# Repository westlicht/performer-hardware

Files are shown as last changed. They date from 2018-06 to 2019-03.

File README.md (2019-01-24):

# PER|FORMER - Hardware Design Files

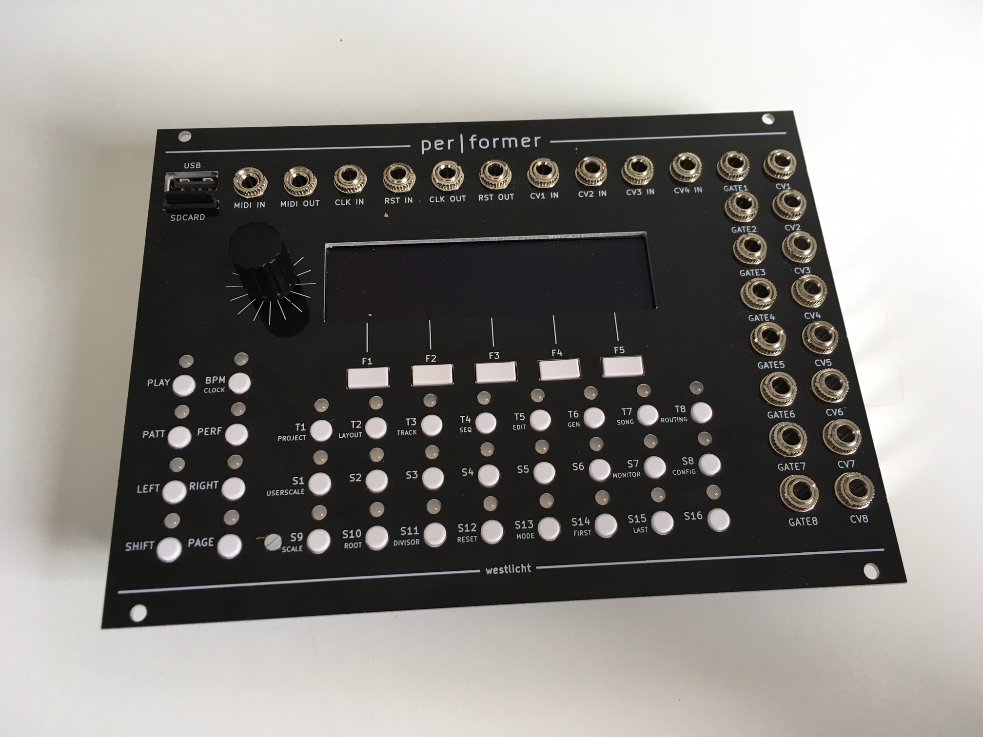
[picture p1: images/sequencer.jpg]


## Overview

This repository contains the hardware design files (KiCad) for the **PER|FORMER** eurorack sequencer.

For more information on the project go [here](https://westlicht.github.io/performer).

The firmware is hosted in a separate repository [here](https://github.com/westlicht/performer).

## Schematic

The schematic is available as a [PDF](https://cdn.rawgit.com/westlicht/performer-hardware/master/sequencer.pdf).

## Physical dimensions

| Board | Width (mm) | Height (mm) |
| --- | --- | --- |
| PCB | 171.45 | 106.68 |
| Frontpanel | 172.5 | 128.27 |

The width of the module is 34 HP in [eurorack standard](http://www.doepfer.de/a100_man/a100m_e.htm).

## Bill of materials

The BOM is available as a [CSV](bom/bom.csv) and [HTML](https://cdn.rawgit.com/westlicht/performer-hardware/master/bom/bom.html). In addition to the parts on the PCB there are a few additional hardware components that are necessary to complete the build, see [here](bom/hardware.csv).

## License

<br />

This work is licensed under a <a rel="license" href="http://creativecommons.org/licenses/by-nc-sa/4.0/">Creative Commons Attribution-NonCommercial-ShareAlike 4.0 International License</a>.

## Images

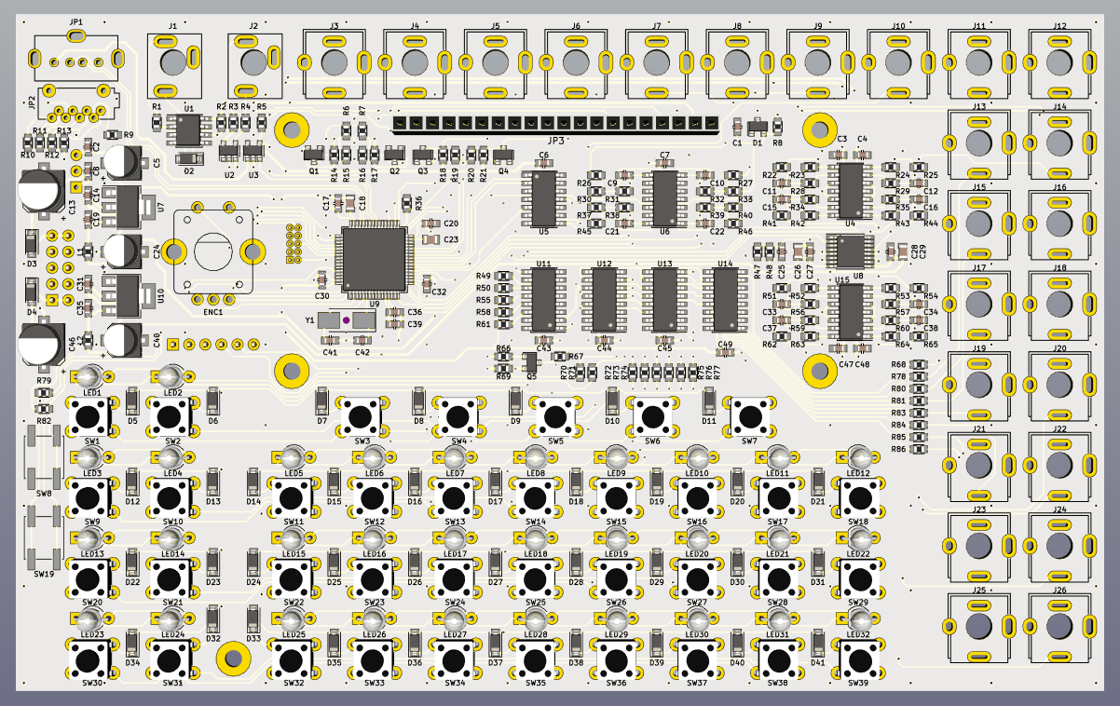
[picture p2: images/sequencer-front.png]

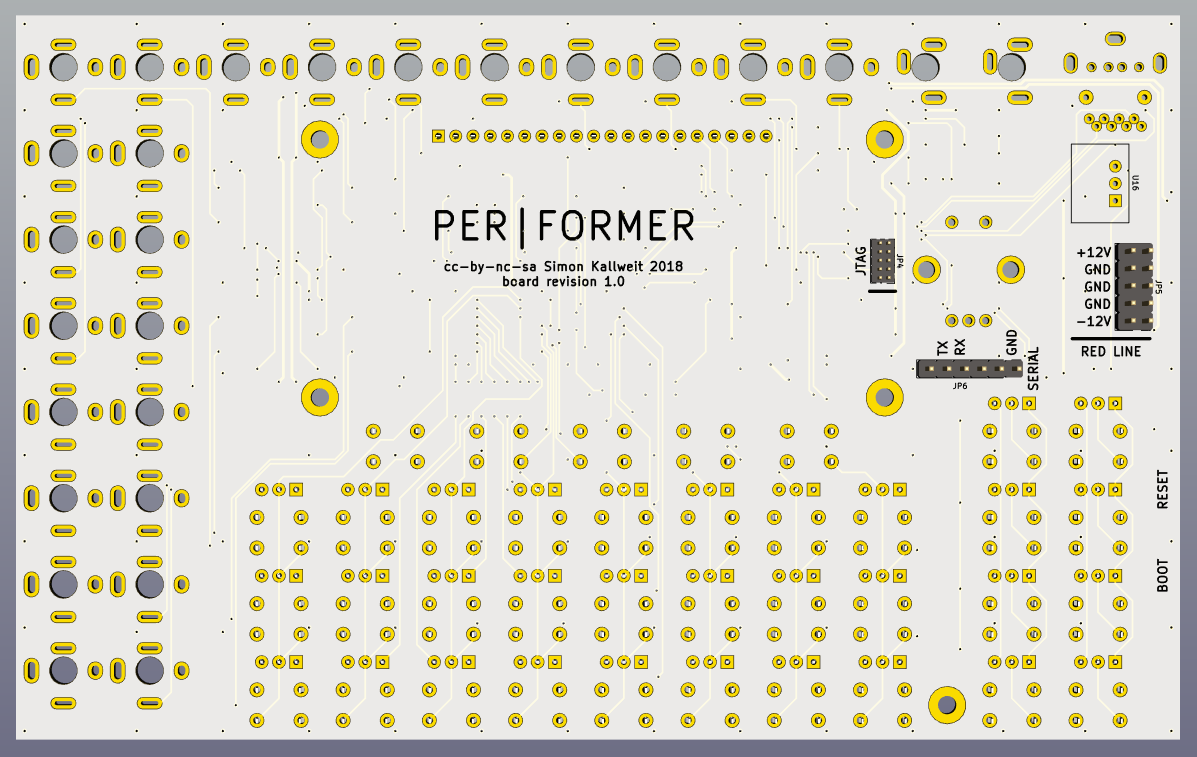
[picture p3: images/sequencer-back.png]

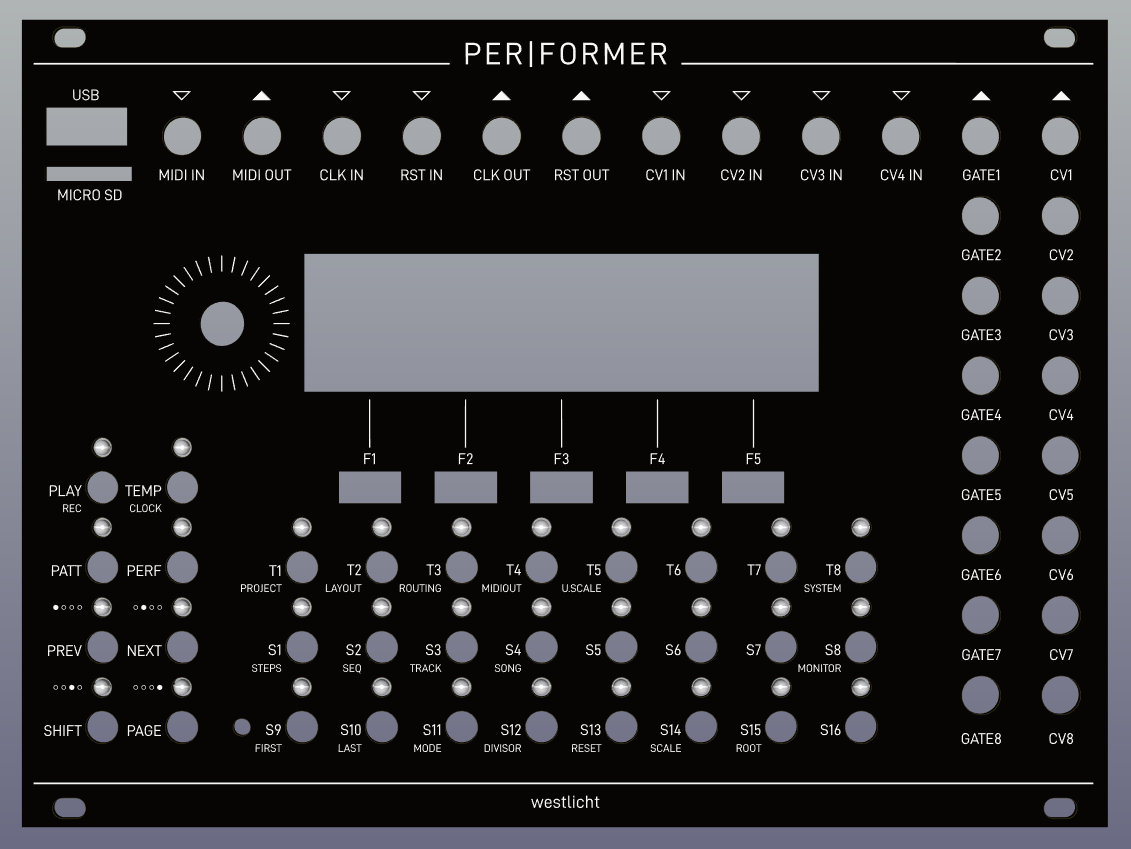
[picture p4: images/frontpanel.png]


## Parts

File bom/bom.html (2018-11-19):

Source File | /Users/freak/Documents/performer-hardware/sequencer.sch
BoM Date | 2018 November 19, Monday 22:16:32
Schematic Version | 1.0
Schematic Date | 2018-10-09
KiCad Version | Eeschema 4.0.7
Component Groups | 46
Component Count (per PCB) | 304
Fitted Components (per PCB) | 304
Number of PCBs | 1
Total Component Count (for 1 PCBs) | 304
 | References | Quantity Per PCB | Value | Package | MFN | MFP | Datasheet
1 | C1 C2 C3 C4 C6 C7 C8 C14 C17 C19 C20 C25 C27 C28 C30 C31 C32 C35 C36 C43 C44 C45 C47 C48 C49 | 25 | 100n | 0603 | Murata | GRM188R71E104JA01J | http://datasheet.octopart.com/GRM188R71E104JA01J-Murata-datasheet-66077098.pdf
2 | C11 C12 C15 C16 C33 C34 C37 C38 C41 C42 | 10 | 18p | 0603 | Murata | GRM1885C1H180JA01J | http://datasheet.octopart.com/GRM1885C1H180JA01J-Murata-datasheet-66077082.pdf
3 | C9 C10 C21 C22 | 4 | 1n | 0603 | Murata | GRM1885C1H102FA01J | http://datasheet.octopart.com/GRM1885C1H102FA01J-Murata-datasheet-66077081.pdf
4 | C39 | 1 | 1u | 0603 | Murata | GRM188R61A105KA61J | http://datasheet.octopart.com/GRM188R61A105KA61J-Murata-datasheet-66077091.pdf
5 | C18 C23 C26 C29 | 4 | 2.2u | 0805 | TDK | C2012X5R1A225K085AA | http://datasheet.octopart.com/C2012X5R1A225K085AA-TDK-datasheet-41194876.pdf
6 | C5 C24 C40 | 3 | 22u | Panasonic C | Panasonic | EEE-FP1E220AR | http://datasheet.octopart.com/EEE-FP1E220AR-Panasonic-datasheet-13268972.pdf
7 | C13 C46 | 2 | 47u | Panasonic D | Panasonic | EEE-FK1V470P | http://datasheet.octopart.com/EEE-FK1V470P-Panasonic-datasheet-13266987.pdf
8 | D2 D5 D6 D7 D8 D9 D10 D11 D12 D13 D14 D15 D16 D17 D18 D19 D20 D21 D22 D23 D24 D25 D26 D27 D28 D29 D30 D31 D32 D33 D34 D35 D36 D37 D38 D39 D40 D41 | 38 | 1N4148 | SOD-123 | Diodes Inc. | 1N4148W-7-F | http://datasheet.octopart.com/1N4148W-7-F-Diodes-Inc.-datasheet-12518151.pdf
9 | D3 D4 | 2 | 1N5819HW | SOD-123 | Diodes Inc. | 1N5819HW-7-F | http://datasheet.octopart.com/1N5819HW-7-F-Diodes-Inc.-datasheet-34441420.pdf
10 | D1 | 1 | LM4040CIM3-10.0 | SOT-23 | Texas Instruments | LM4040CIM3-10.0/NOPB | http://www.ti.com/product/lm4040-n/technicaldocuments?HQS=TI-null-null-octopart-df-pf-null-wwe
11 | ENC1 | 1 | PEC11R |  | Bourns | PEC11R-4220F-S0024 | http://datasheet.octopart.com/PEC11R-4220F-S0024-Bourns-datasheet-68303416.pdf
12 | J3 J4 J5 J6 J7 J8 J9 J10 J11 J12 J13 J14 J15 J16 J17 J18 J19 J20 J21 J22 J23 J24 J25 J26 | 24 | PJ301BM |  | Wenzhou QingPu Electronics | WQP-PJ301BM | http://www.qingpu-electronics.com/en/products/wqp-pj3010bm-34.html
13 | J1 J2 | 2 | PJ301CM |  | Wenzhou QingPu Electronics | WQP-PJ301CM | http://www.qingpu-electronics.com/en/products/WQP-PJ301CM-40.html
14 | JP4 | 1 | JTAG |  | FCI | 20021111-00010T4LF | http://datasheet.octopart.com/20021111-00010T4LF-FCI-datasheet-11548804.pdf
15 | JP3 | 1 | NHD-3.12-25664UC |  | Newhaven Display | NHD-3.12-25664UCY2 | http://datasheet.octopart.com/NHD-3.12-25664UCY2-Newhaven-Display-datasheet-10504909.pdf
16 | JP2 | 1 | PJS008U-3000 |  | Yamaichi | PJS008U-3000-0 | http://datasheet.octopart.com/PJS008U-3000-0-Yamaichi-datasheet-32042463.pdf
17 | JP5 | 1 | POWER |  | FCI | 67996-410HLF | http://datasheet.octopart.com/67996-410HLF-Areva-datasheet-10288749.pdf
18 | JP6 | 1 | Serial / Bootloader |  | FCI | 68002-106HLF | http://datasheet.octopart.com/68002-106HLF-FCI-datasheet-8449737.pdf
19 | JP1 | 1 | USB_A |  | Molex | 105057-0001 | http://datasheet.octopart.com/105057-0001-Molex-datasheet-48881000.pdf
20 | L1 L2 | 2 | Bead | 0603 | Laird | MI0603K300R-10 | http://datasheet.octopart.com/MI0603K300R-10-Steward-datasheet-14357321.pdf
21 | LED1 LED2 LED3 LED4 LED5 LED6 LED7 LED8 LED9 LED10 LED11 LED12 LED13 LED14 LED15 LED16 LED17 LED18 LED19 LED20 LED21 LED22 LED23 LED24 LED25 LED26 LED27 LED28 LED29 LED30 LED31 LED32 | 32 | LTL1BEKVJNN |  | Lite-On | LTL1BEKVJNN | http://datasheet.octopart.com/LTL1BEKVJNN-Lite-On-datasheet-25352782.pdf
22 | Q1 Q2 Q3 Q4 Q5 | 5 | MMBT3904 | SOT-23 | ON Semiconductor | MMBT3904LT1G | http://datasheet.octopart.com/MMBT3904LT1G-ON-Semiconductor-datasheet-11971584.pdf
23 | R14 R17 R26 R27 R28 R29 R34 R35 R45 R46 R56 R57 R59 R60 R69 | 15 | 100k | 0603 | Panasonic | ERJ-3EKF1003V | http://datasheet.octopart.com/ERJ-3EKF1003V-Panasonic-datasheet-82288794.pdf
24 | R2 R5 R6 R7 R19 R20 R36 R49 R50 R55 R58 R61 R66 R67 R79 R82 | 16 | 10k | 0603 | Panasonic | ERJ-3EKF1002V | http://datasheet.octopart.com/ERJ-3EKF1002V-Panasonic-datasheet-13266541.pdf
25 | R9 R15 R16 | 3 | 1M | 0603 | Panasonic | ERJ-3EKF1004V | http://datasheet.octopart.com/ERJ-3EKF1004V-Panasonic-datasheet-13266541.pdf
26 | R8 R18 R21 R68 R70 R71 R72 R73 R74 R75 R76 R77 R78 R80 R81 R83 R84 R85 R86 | 19 | 1k | 0603 | Panasonic | ERJ-3EKF1001V | http://datasheet.octopart.com/ERJ-3EKF1001V-Panasonic-datasheet-82288794.pdf
27 | R30 R33 R37 R40 | 4 | 200k | 0603 | Panasonic | ERJ-3EKF2003V | http://datasheet.octopart.com/ERJ-3EKF2003V-Panasonic-datasheet-13266541.pdf
28 | R1 R3 R4 R23 R24 R42 R43 R52 R53 R63 R64 | 11 | 220 | 0603 | Panasonic | ERJ-3EKF2200V | http://datasheet.octopart.com/ERJ3EKF2200V-Panasonic-datasheet-13266541.pdf
29 | R47 | 1 | 22k | 0603 | Panasonic | ERJ-3EKF2202V | http://datasheet.octopart.com/ERJ3EKF2202V-Panasonic-datasheet-13266541.pdf
30 | R22 R25 R41 R44 R51 R54 R62 R65 | 8 | 24k | 0603 | Panasonic | ERJ-3EKF2402V | http://datasheet.octopart.com/ERJ-3EKF2402V-Panasonic-datasheet-82288794.pdf
31 | R10 R11 R12 R13 R31 R32 R38 R39 R48 | 9 | 33k | 0603 | Panasonic | ERJ-3EKF3302V | http://datasheet.octopart.com/ERJ3EKF3302V-Panasonic-datasheet-13266541.pdf
32 | SW8 SW19 | 2 | EVQQ2 |  | Panasonic | EVQ-Q2K01W | http://datasheet.octopart.com/EVQ-Q2K01W-Panasonic-datasheet-13267673.pdf
33 | SW1 SW2 SW3 SW4 SW5 SW6 SW7 SW9 SW10 SW11 SW12 SW13 SW14 SW15 SW16 SW17 SW18 SW20 SW21 SW22 SW23 SW24 SW25 SW26 SW27 SW28 SW29 SW30 SW31 SW32 SW33 SW34 SW35 SW36 SW37 SW38 SW39 | 37 | TL1105 |  | E-Switch | TL1105SPF160Q | http://datasheet.octopart.com/TL1105SPF160Q-E-Switch-datasheet-502092.pdf
34 | U11 | 1 | 74HC165 | SOIC-16 | Texas Instruments | SN74HC165D | https://octopart.com/click/track?ct=datasheets&hlid=24916538&ppid=35776&sid=370&sig=03765d0
35 | U12 U13 U14 | 3 | 74HC595 | SOIC-16 | Texas Instruments | SN74HC595D | https://octopart.com/click/track?ct=datasheets&hlid=24917219&ppid=44183&sid=370&sig=036bbbe
36 | U5 | 1 | 74HCT125 | SOIC-14 | Texas Instruments | SN74HCT125D | https://octopart.com/click/track?ct=datasheets&hlid=24917456&ppid=464455&sid=370&sig=085083f
37 | U2 | 1 | 74LV1T34 | SOT-23-5 | Texas Instruments | SN74LV1T34DBVR | https://octopart.com/click/track?ct=datasheets&hlid=24919287&ppid=33260490&sid=370&sig=060f3df
38 | U8 | 1 | DAC8568C | TSSOP-16 | Texas Instruments | DAC8568ICPW | https://octopart.com/click/track?ct=datasheets&hlid=24881192&ppid=10447789&sid=370&sig=0a14fa8
39 | U7 U10 | 2 | LM1117-3.3 | SOT-223 | Texas Instruments | LM1117MP-3.3/NOPB | https://octopart.com/click/track?ct=datasheets&hlid=24885394&ppid=24812450&sid=370&sig=0f3ff9a
40 | U6 | 1 | MCP6004 | SOIC-14 | Microchip | MCP6004-I/SL | http://datasheet.octopart.com/MCP6004-I/SL-Microchip-datasheet-8823409.pdf
41 | U4 U15 | 2 | OPA4172 | SOIC-14 | Texas Instruments | OPA4172IDR | https://octopart.com/click/track?ct=datasheets&hlid=24903049&ppid=47153707&sid=370&sig=086dfac
42 | U16 | 1 | R-78E5.0-1.0 |  | Recom Power | R-78E5.0-1.0 | http://datasheet.octopart.com/R-78E5.0-1.0-Recom-Power-datasheet-68298118.pdf
43 | U9 | 1 | STM32F405RGTx | LQFP-64 | STMicroelectronics | STM32F405RGT6 | http://datasheet.octopart.com/STM32F405RGT6-STMicroelectronics-datasheet-12357803.pdf
44 | U3 | 1 | STMPS2151 | SOT-23-5 | STMicroelectronics | STMPS2151STR | http://datasheet.octopart.com/STMPS2151STR-STMicroelectronics-datasheet-15207125.pdf
45 | U1 | 1 | VO0600T | SOIC-8 | Vishay | VO0600T | http://datasheet.octopart.com/VO0600T-Vishay-datasheet-8549194.pdf
46 | Y1 | 1 | 8MHz |  | Abracon | ABM3-8.000MHZ-D2Y-T | http://datasheet.octopart.com/ABM3-8.000MHZ-D2Y-T-Abracon-datasheet-8815637.pdf

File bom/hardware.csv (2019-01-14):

Component | References | Quantity Per PCB | Value | MFP | MFN | Datasheet
1 | LCD Connector Female | 1 | 20P | 929870-01-20-RA | 3M | http://datasheet.octopart.com/929870-01-20-RA-3M-datasheet-167403.pdf
2 | LCD Connector Male | 1 | 20P | 68002-120HLF | FCI | http://datasheet.octopart.com/68002-120HLF-FCI-datasheet-8449737.pdf
3 | Round Switch Caps | 32 | 1RWHT | 1RWHT | E-Switch | http://datasheet.octopart.com/1RWHT-E-Switch-datasheet-12523944.pdf
4 | Rectangular Switch Caps | 5 | 1CWHT | 1CWHT | E-Switch | https://datasheet.octopart.com/1CWHT-E-Switch-datasheet-44138771.pdf
5 | Rotary Knob | - | - | - | - | https://www.thonk.co.uk/shop/sifam-soft-touch-encoder-knobs/
6 | M2.5 Standoff 7mm | 4 | - | R25-1000702 | Harwin | http://datasheet.octopart.com/R25-1000702-Harwin-datasheet-155401.pdf
7 | M2.5 Standoff 11mm | 1 | - | R25-1001102 | Harwin | http://datasheet.octopart.com/R25-1001102-Harwin-datasheet-14706888.pdf
8 | M2.5 Screw | 10 | 29300 | Keystone | http://datasheet.octopart.com/29300-Keystone-datasheet-43872458.pdf

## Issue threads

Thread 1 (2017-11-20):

Replace MCP6004 with TL074

westlicht, 2017-11-20:
MCP6004 has max +/-6V power supply, but it's sourced from +/-12V, so just replace with pin-compatible TL074.

Closed 2017-11-20.

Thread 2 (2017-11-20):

Replace 0603 footprints

westlicht, 2017-11-20:
0603 footprints are really small, especially for hand-soldering. Should be replaced with larger footprints for the DIY version!

Closed 2018-05-16.

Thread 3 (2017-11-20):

Fix USB connector cutout

westlicht, 2017-11-20:
The cutout on the frontpanel for the USB connector is too large.

Closed 2018-05-16.

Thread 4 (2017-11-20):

Fix PJ301CM footprint

westlicht, 2017-11-20:
While the footprint is correct, the alignment to the frontpanel cutout is not.

Closed 2019-03-19.

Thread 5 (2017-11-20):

Replace jack connectors with thonkiconns

westlicht, 2017-11-20:
Thonk will soon stock the stereo version of the thonkiconn jack, so this might be a better alternative to the current jacks.

westlicht, 2019-03-19:
The footprint is too large to make for a neat design. Will keep the jacks as is for now.

Closed 2019-03-19.

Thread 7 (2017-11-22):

Consider replacing DAC8568C with DAC8568A

westlicht, 2017-11-22:
The C grade have 5V full scale output, but due to VCC at 3.3V we only use half range at 2.5V and loose 1 bit of accuracy. We could replace with DAC8568A which has full range at 2.5V, so this would allow us to use all bits, however, we use some accuracy due to lower grade of internal reference.

8bitPig, 2019-08-20:
Aren't we loosing 8bits of accuracy?
Still worth the higher temp drift even considering the 33k/22k Voltage divider (each resistor has 100-150ppm) for Vbias which then gets gained times 4.

btomwhitehead, 2020-01-29:
Resurrecting an old issue here but thought I its a pertinent place to raise it. If you dont think so, Im happy to delete my comment.

I made the mistake of getting a DAC8568B, which like A, doesn't have the 2x output gain. I am not worried about the initialisation value being at midpoint given the firmware appears to init the Dac to 0v regardless.

So the two options are:
- Replace the DAC (and there will be an effective 15bit resolution)
- Update firmware to reflect the reduced output gain.

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

From my understanding of this issue and the effective output in the datasheet, it seems that the leading bit is irrelevant because the VCC is less than the 5v range. My thought it then that the gain can be made up with writing double the DATA value to the DAC. If this is true, if we reduce the right data bitwise shifts in the Dac write by 1, we can effectively make up the range:
```
void Dac::writeDac(uint8_t command, uint8_t address, uint16_t data, uint8_t function) {
    uint8_t b1 = command;
    uint8_t b2 = (address << 4) | (data >> 12);
    uint8_t b3 = data >> 4;
    uint8_t b4 = (data & 0xf) << 4 | function;
  ...
```
to
```
void Dac::writeDac(uint8_t command, uint8_t address, uint16_t data, uint8_t function) {
    uint8_t b1 = command;
    uint8_t b2 = (address << 4) | (data >> 11);
    uint8_t b3 = data >> 3;
    uint8_t b4 = ((data << 1) & 0xf) << 4 | function;
  ...
```
Do you think this could work? I am going to give it a test in the coming days. Or do you know a better place (this is no doubt a hack) to make such a change?

🙏 🙏 🙏

westlicht, 2020-03-29:
Hey, I only saw this comment now. I think the change you did is valid, shifting the output by one bit. I might consider adding that to the hardware config so people can actually use the cheaper DAC if the wish to. I haven't measured the difference in accuracy, would have to first make a performer with the A grade DAC.

btomwhitehead, 2020-03-29:
Great!

Yeah, I have been using it since without any complaints or noticeable drift.

Thanks for the response.

Timnuge, 2020-04-10:
Hello!

My Performer is built with DAC8568A🤔 A way to switch would make my life easy or, could you please share with me update file? Any help would be greatly appreciated!

btomwhitehead, 2020-04-10:
@Timnuge as per above notes, heres the changes I made to `src/platform/stm32/drivers/Dac.cpp`:

```
--- a/src/platform/stm32/drivers/Dac.cpp
+++ b/src/platform/stm32/drivers/Dac.cpp
@@ -72,9 +72,9 @@ void Dac::write() {

 void Dac::writeDac(uint8_t command, uint8_t address, uint16_t data, uint8_t function) {
     uint8_t b1 = command;
-    uint8_t b2 = (address << 4) | (data >> 12);
-    uint8_t b3 = data >> 4;
-    uint8_t b4 = (data & 0xf) << 4 | function;
+    uint8_t b2 = (address << 4) | (data >> 11);
+    uint8_t b3 = data >> 3;
+    uint8_t b4 = ((data << 1) & 0xf) << 4 | function;

     gpio_clear(DAC_PORT, DAC_SYNC);--- a/src/platform/stm32/drivers/Dac.cpp
```

Would have pushed a custom branch to the main repo but (very sensibly) I don't have the requisite permissions.

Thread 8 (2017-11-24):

Fix LED Matrix

westlicht, 2017-11-24:
The LED matrix is flawed. The 74HC595 cannot sink the current of 8 LEDs in a row. Possible solutions:
- sinking 74HC595 with a part like TPIC6x595
- add a darlington array to allow sinking more current

Make sure that sourcing current for the LEDs is within the specs of the 74HC595, otherwise we also need to increase sourcing capability.

westlicht, 2018-05-16:
Using low power leds instead.

Closed 2018-05-16.

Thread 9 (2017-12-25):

Replace 74HC with 74HCT

westlicht, 2017-12-25:
Use TTL versions of shift registers and remove the level shifter IC. Also, connect OE pins to STM32 to allow disabling the matrix.

westlicht, 2018-05-16:
Using lower power leds instead.

Closed 2018-05-16.

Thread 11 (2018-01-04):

Fix SDCard

westlicht, 2018-01-04:
- add 10k pullups to all signals
- move SDIO_CMD from pin 2 to pin 3
- add card detect line

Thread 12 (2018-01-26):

Rework power supply

westlicht, 2018-01-26:
The 5V regulator overheats due to excessive power dissipation. The linear regulator needs to replaced with a dc/dc step down regulator with higher efficiency.

- use step down to generate 5V at 1A for the whole module
- feed 3.3V regulators from the 5V supply
- a possible part is the RECOM R-78E-1.0 (https://www.recom-power.com/pdf/Innoline/R-78Exx-1.0.pdf) although the package height is 10.4mm which barley fits below the front panel and would be too high when using THONKICONN connectors

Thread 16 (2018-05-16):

Move Recom DCDC to PCB top side

westlicht, 2018-05-16:
This is problematic because the part does not fit below the frontpanel. One solution would be to mill a 1mm groove on the backside of the frontpanel (as done in newer Mutable Instruments modules).

Closed 2019-03-19.

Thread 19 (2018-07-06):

Front panel issue

themangoest, 2018-07-06:
There seems to be an issue with the front panel. The v-cut line is missing.

westlicht, 2018-07-23:
What do you mean by that? v-cut is necessary to break apart pcbs, right? There is an Edge.Cuts layer which should be enough. Just as a note, I'm reworking the frontpanel at the moment, you should wait for the final design if you want proper labeling.

Closed 2019-03-19.

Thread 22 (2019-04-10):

Fix crystal capacitors

westlicht, 2019-04-10:
Use correct capacitor value for loading capacitance of crystal. 33pf 50V NP0 is a good value.

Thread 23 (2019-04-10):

Fix clock/reset input

westlicht, 2019-04-10:
Multiple levels of improving current design:
- add protection diode to prevent negative voltage on transistor base
- add LM311 to add proper protection and hysteresis

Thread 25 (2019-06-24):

REV 1 board completely dead

pbizzlr, 2019-06-24:
2x rev 1 boards completely dead.  I have the correct power at the headers and flashed the chips successfully but neither the screen or LEDs show show boot up indication, in fact nothing at all.

ob1techno, 2019-06-24:
I don't think this is an issue with the board. I've built more than one of the rev 1 boards and they work just fine.

pbizzlr, 2019-06-24:
theres a few on fb having similar issues, just wanted to eliminate the possibility. im just concerned theres not even a flicker of an led or screen.

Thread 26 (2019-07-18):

Hardware expansion suggestions

sunflowr, 2019-07-18:
Here's a few ideas I was thinking of if there ever will be a mk2 or whatever:

Internal linking between multiple performers so they stay in sync without having to patch between them, with something like i2c or similar they could also share data so lets say one could modulate the other or similar.

Expansion port for (could be the same as the internal linking) e.g. i2c or similar for allowing to expand the module with more gate/cv in/out.

Maybew i2c trs jack on the front for things like the 16n faderbank (https://16n-faderbank.github.io/) to allow for controlling the performer?

sunflowr, 2019-07-19:
It would also be nice with (preferably software) configurable output levels.
CV: -5 to 5 like now as well as 0 to 10.
Gate: 5 like now or 10 (some gear I got wont trigger on 5)

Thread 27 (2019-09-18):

Curve Track Step Size

mremusic, 2019-09-18:
It would be a big time-saver if there was a way to spread a curve over multiple steps, set by F5.

e.g. you could have a slow ramp over - let‘s say 8 steps - without having to manually set min and max with each of the following steps, but still had the fine step size for quick modulation (rather than changing the divisor).

mremusic, 2019-09-18:
sorry wrong repository

Closed 2019-09-18.

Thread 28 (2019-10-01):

Hardware supervisor

forestcaver, 2019-10-01:
As you are revising the hardware, in lieu of other solutions, it may be worth adding a hardware supervisor eg a mic803 (along with its 10k resistor and 100nf cap).
I added one to my performer and it resolved all my troublesome bootup issues. Not had a single failed boot since adding it.

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

grantHarris, 2020-11-23:
I have to echo this. I built a performer and it doesn't seem to come up properly on about 1 in 10 boots. Blank or white noise on the screen. Unresponsive.

grantHarris, 2020-11-23:
I'd be happy to submit a PR for this if the approach is supported

forestcaver, 2020-11-23:
A lot of people (see muff wiggler thread and fb group) have adopted this approach without any problems. I’ve had no issue with mine since adding it. (I tried fw mods first with no joy). There are board revisions floating around with this mod now. I suspect that, for Simon, revising the hardware is a pretty expensive thankless task as he’d need to order, build and then test any revision; so I totally understand why it hasnt been revised. The best way may be for you to just fork it... there are quite a few hardware mods that would be great to see one day...

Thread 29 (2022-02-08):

Rev 1 board dead.

orys, 2022-02-08:
It was working perfectly and now will not power on.
Don't know where to start. I bought this second hand a week ago.

forestcaver, 2022-02-08:
It’s a non-commercial licence so there shouldnt be second hand modules.
But it’s diy so download the schematics and board files, break out the multimeter and oscilloscope! Start with the power rails and rails regulated from them…. Check over the board under high magnification. If the mcu is alive then run the on chip debugger maybe?
Sometimes the mcu doesnt start if the power on slew is too great - you could try a different psu or add a mic803…. I’ve seen a couple of cases of firmware becoming corrupted but that seems unlikely…
There are loads of possibilities why it may not work and you’ll need to narrow it down….

orys, 2022-02-08:
My friend I bought it from someone. Sorry.
I have opened it up but I'm not an electrician and at 49 I barely see to solder anymore such small components.
I would be grateful if I cound send it to someone to fix it for me and I pay him for his labour.
I got this to start a new system and my dreams are dying right now. :(

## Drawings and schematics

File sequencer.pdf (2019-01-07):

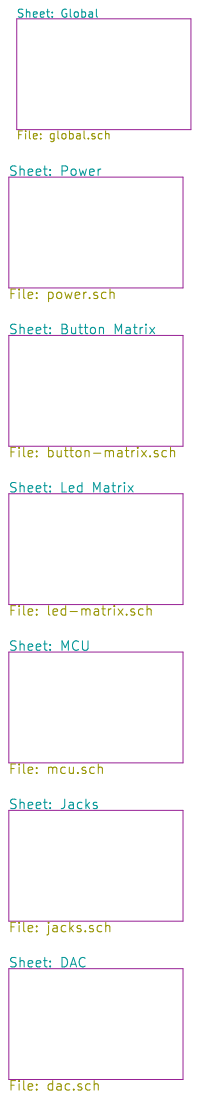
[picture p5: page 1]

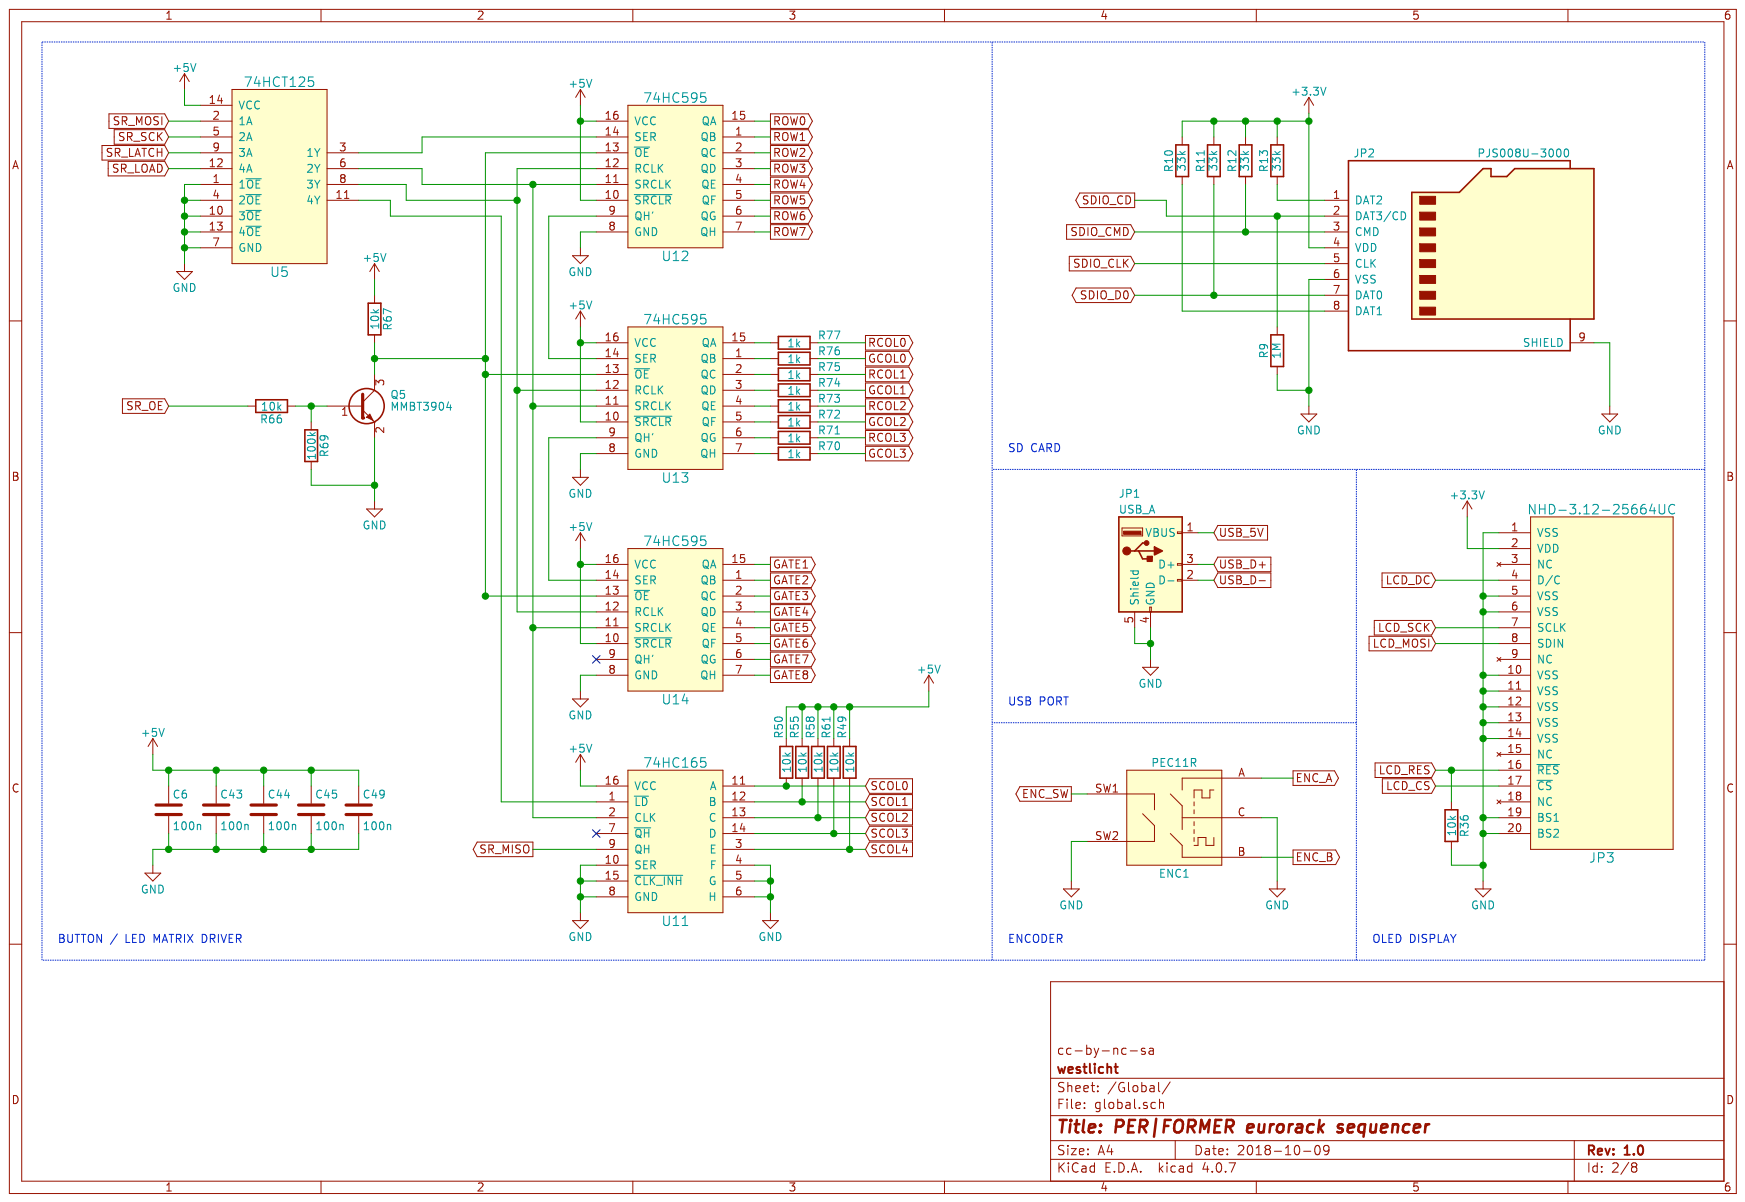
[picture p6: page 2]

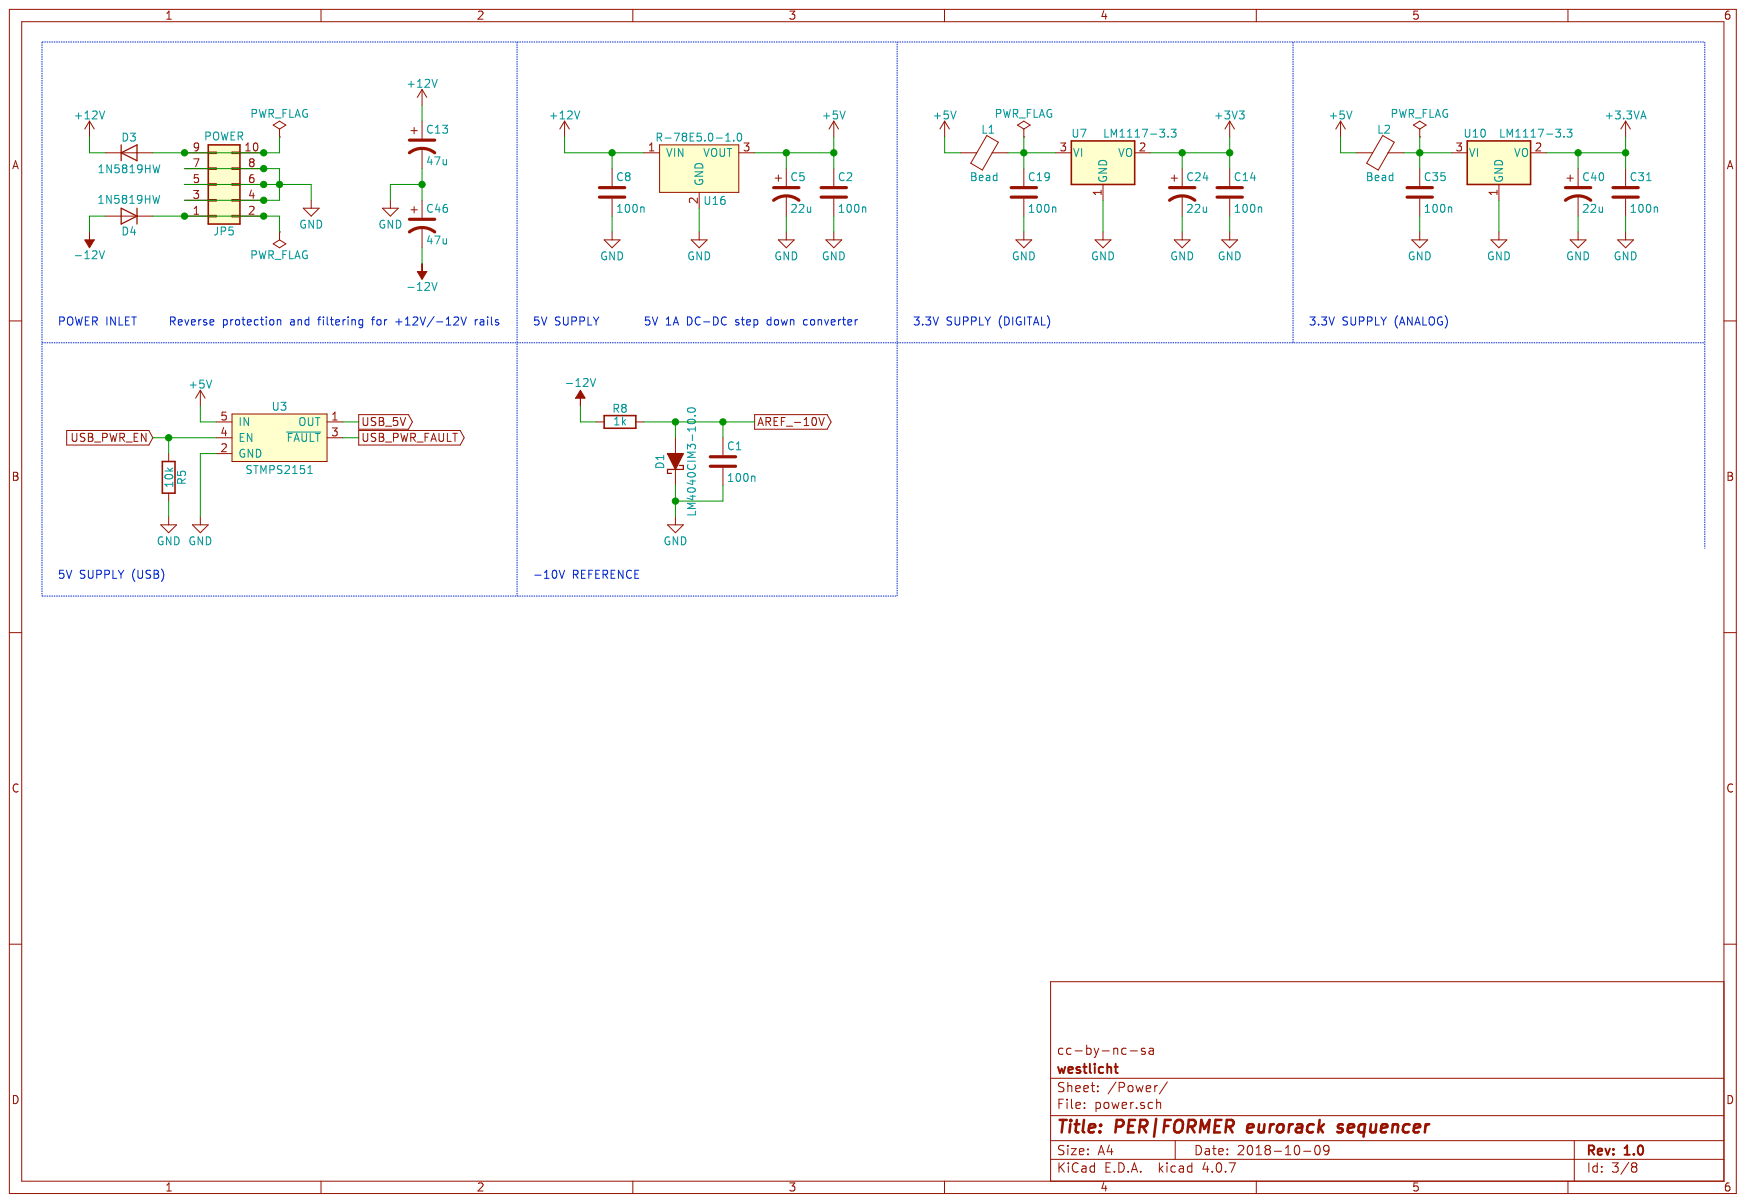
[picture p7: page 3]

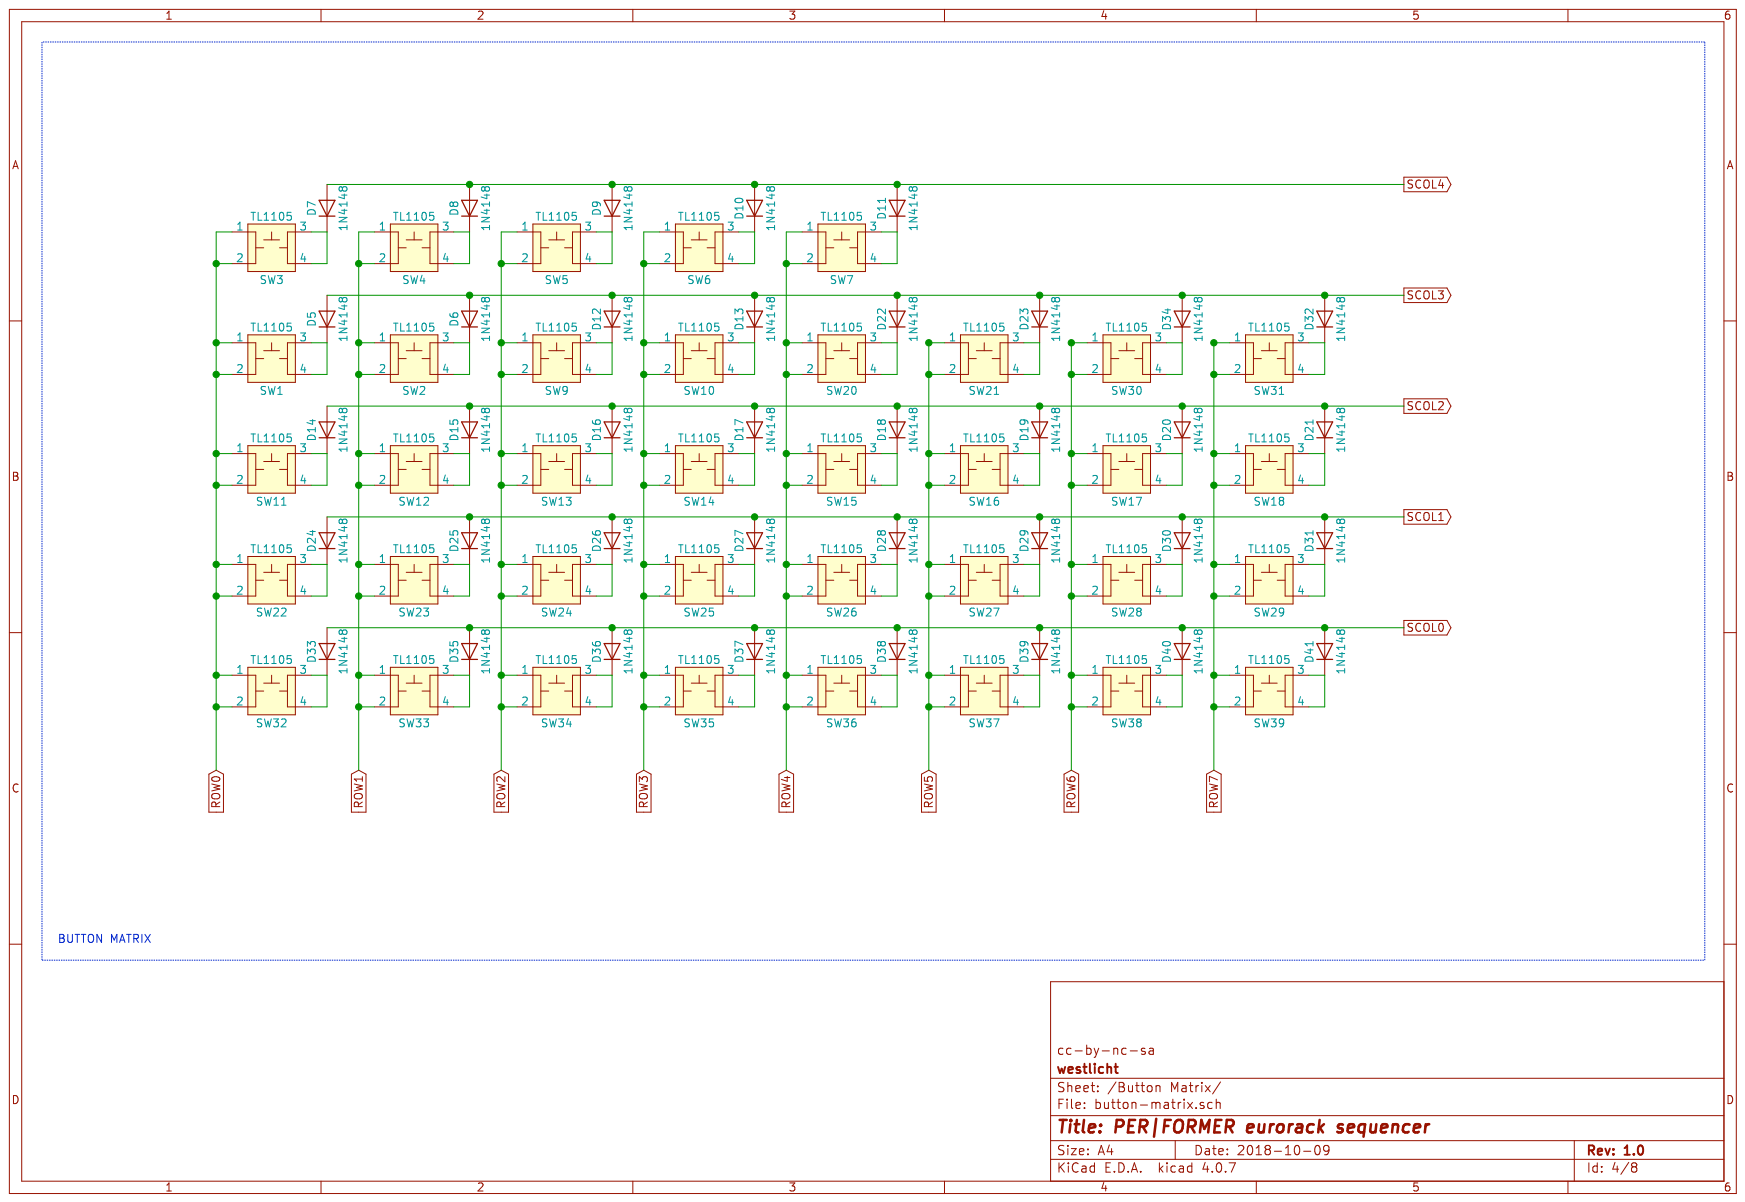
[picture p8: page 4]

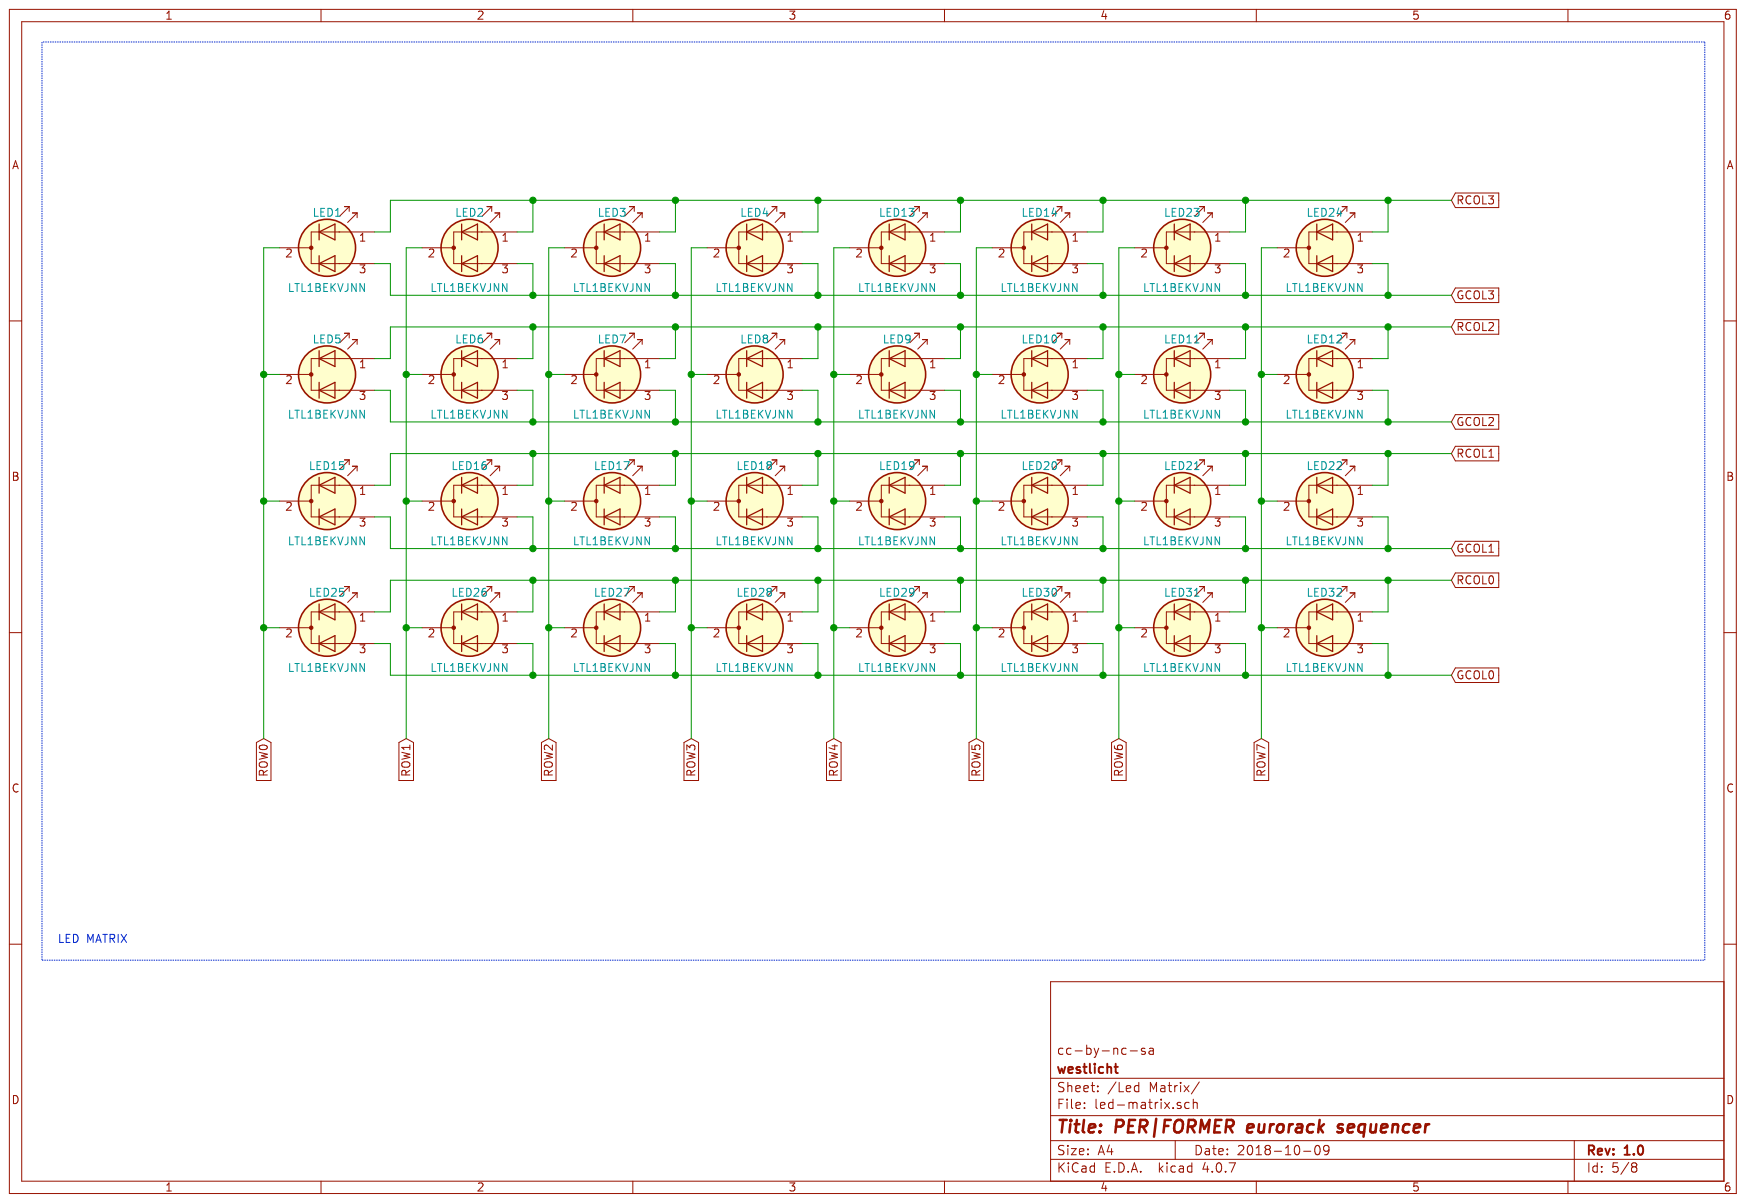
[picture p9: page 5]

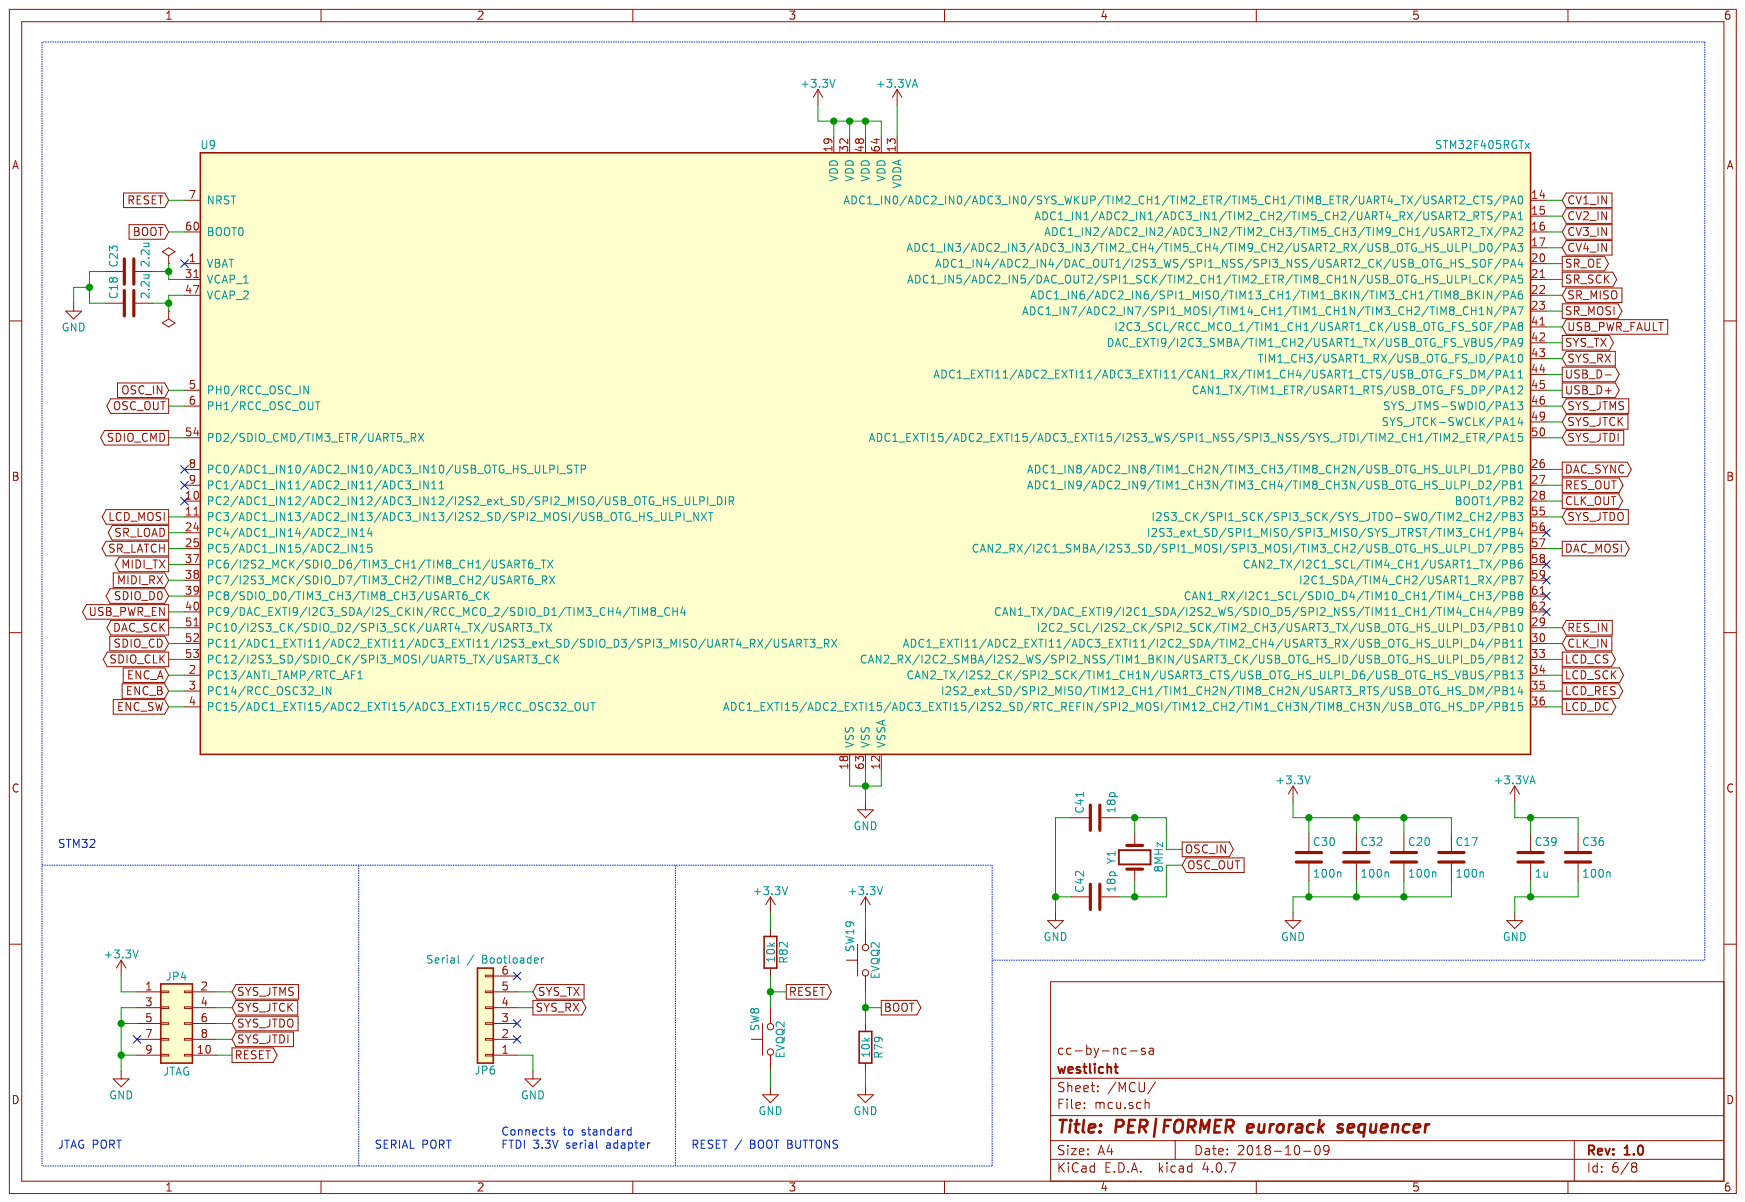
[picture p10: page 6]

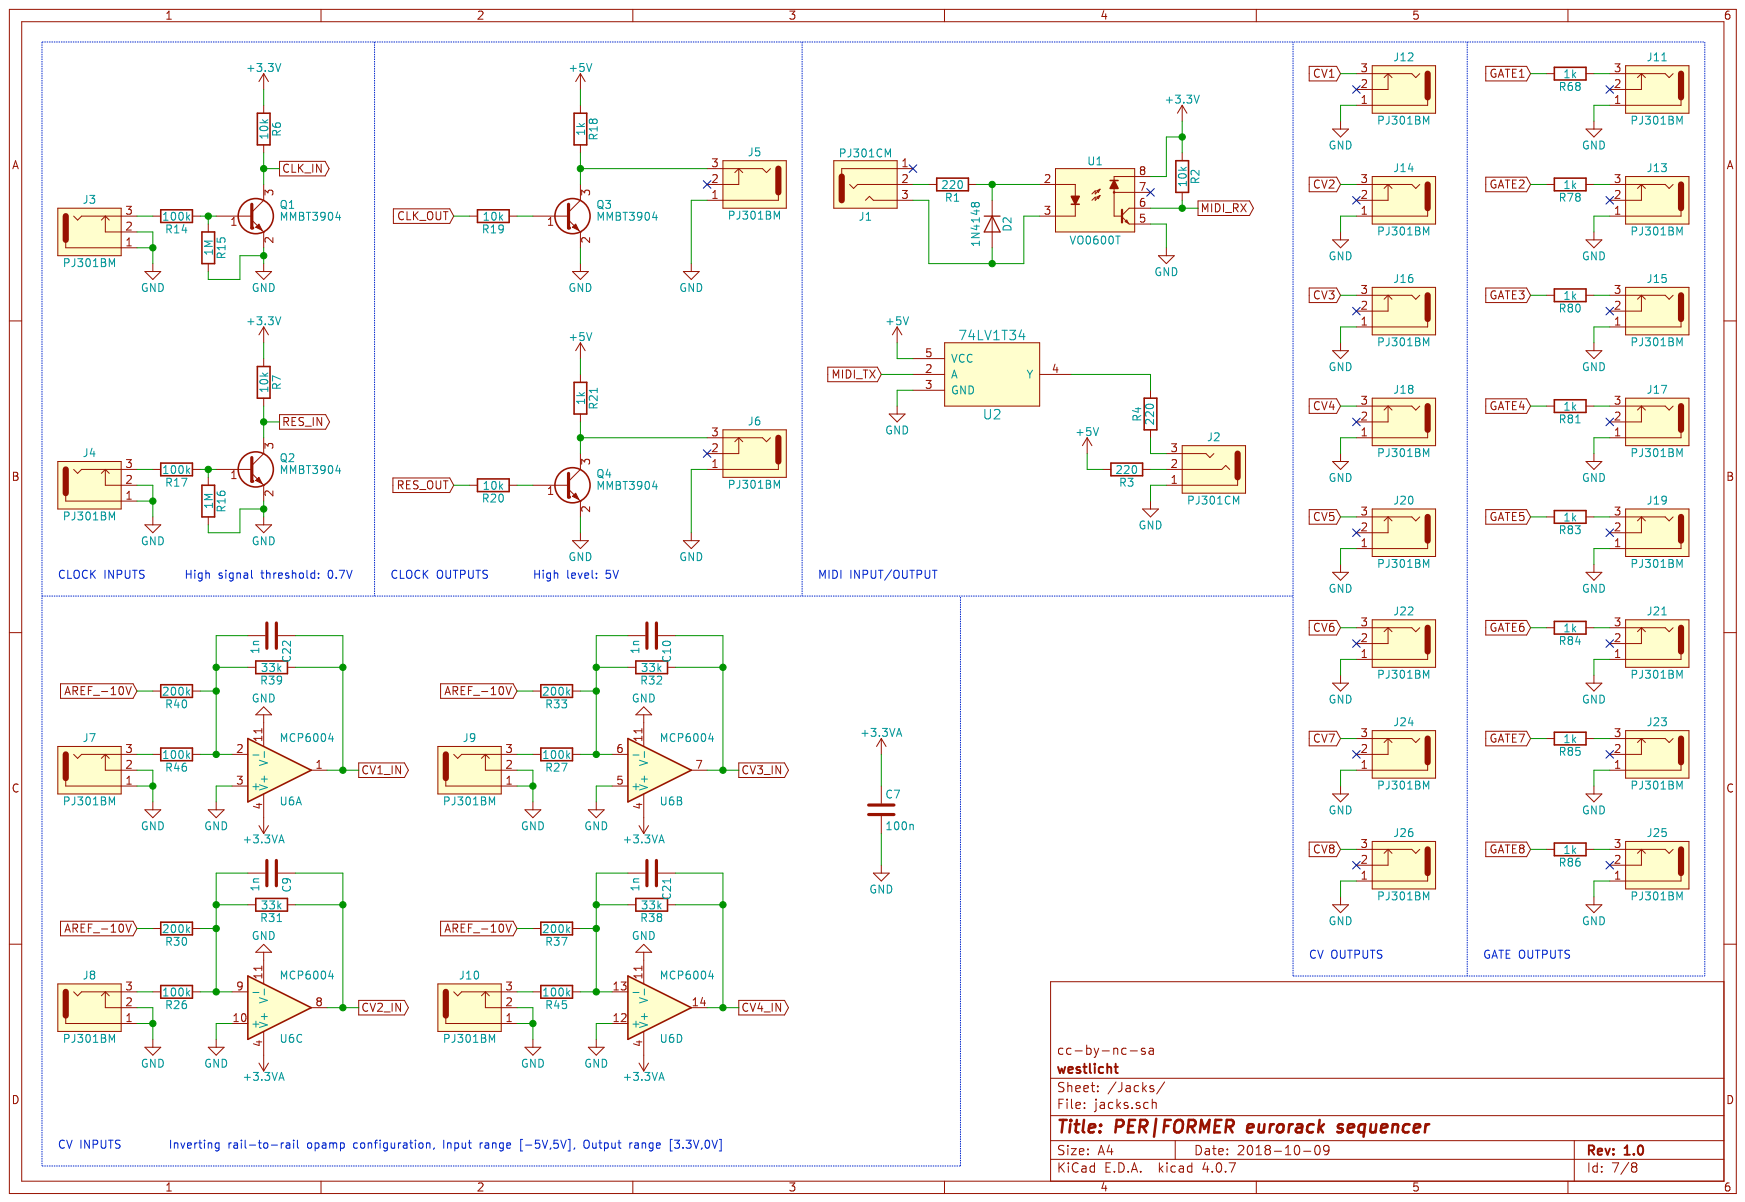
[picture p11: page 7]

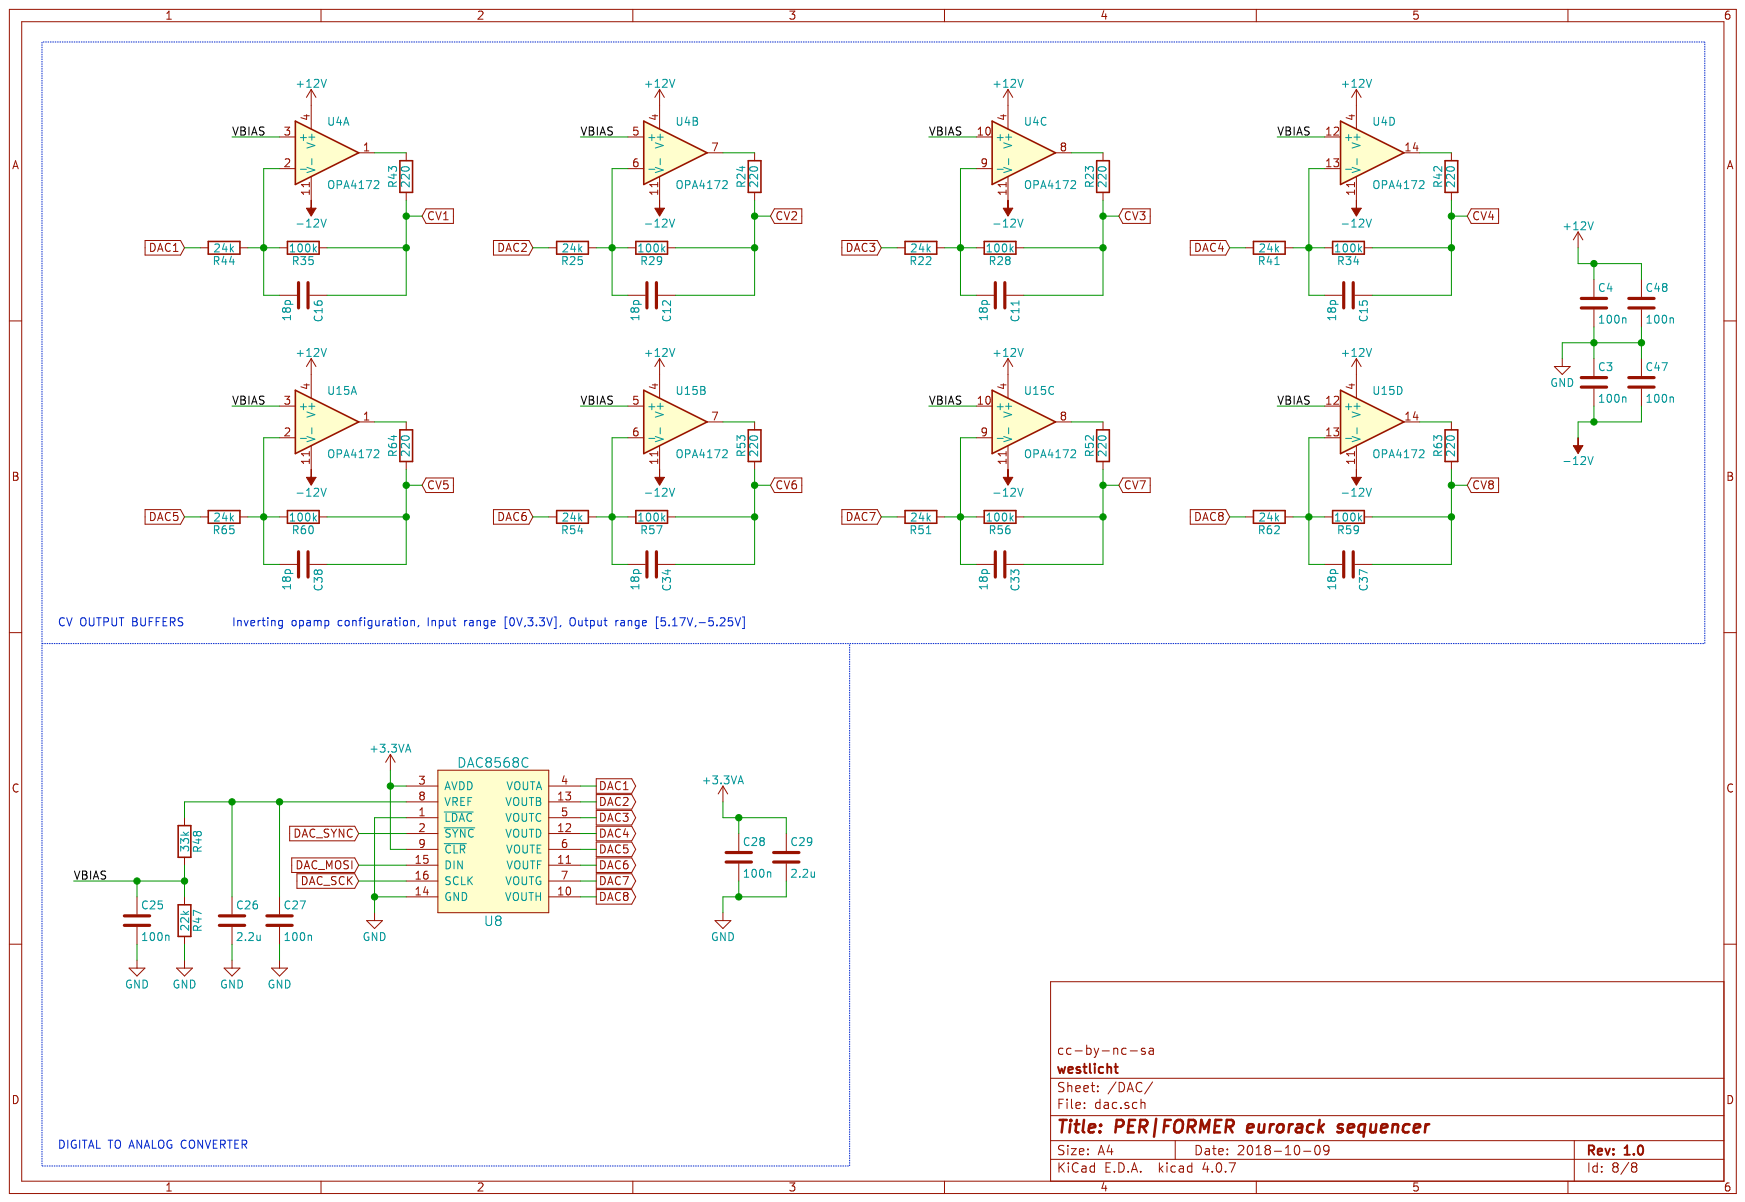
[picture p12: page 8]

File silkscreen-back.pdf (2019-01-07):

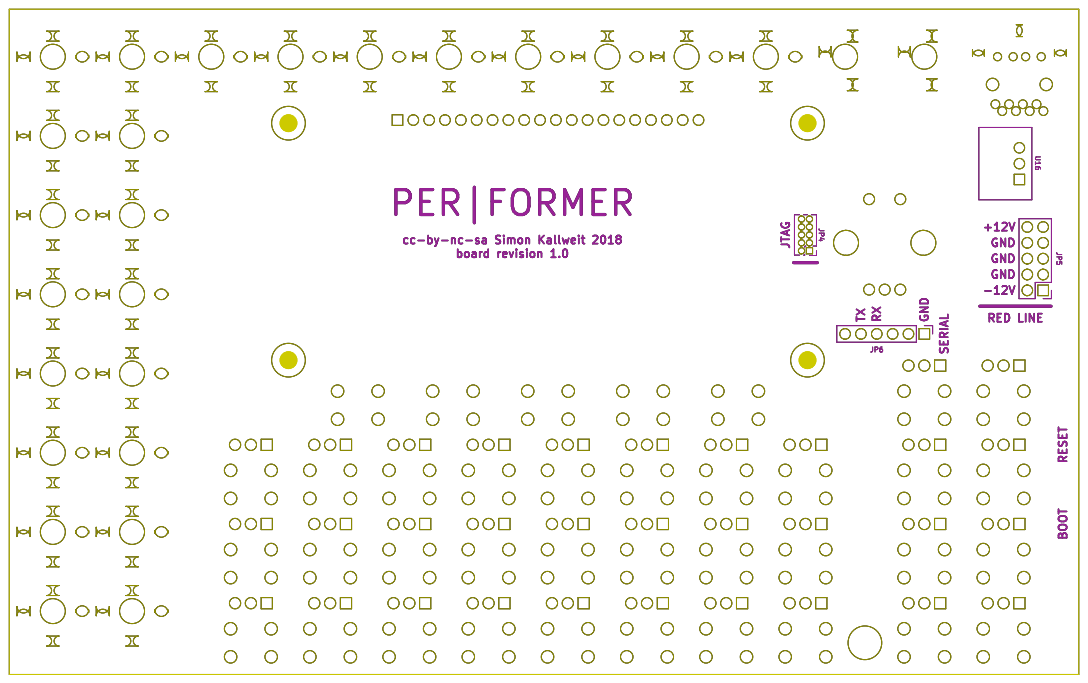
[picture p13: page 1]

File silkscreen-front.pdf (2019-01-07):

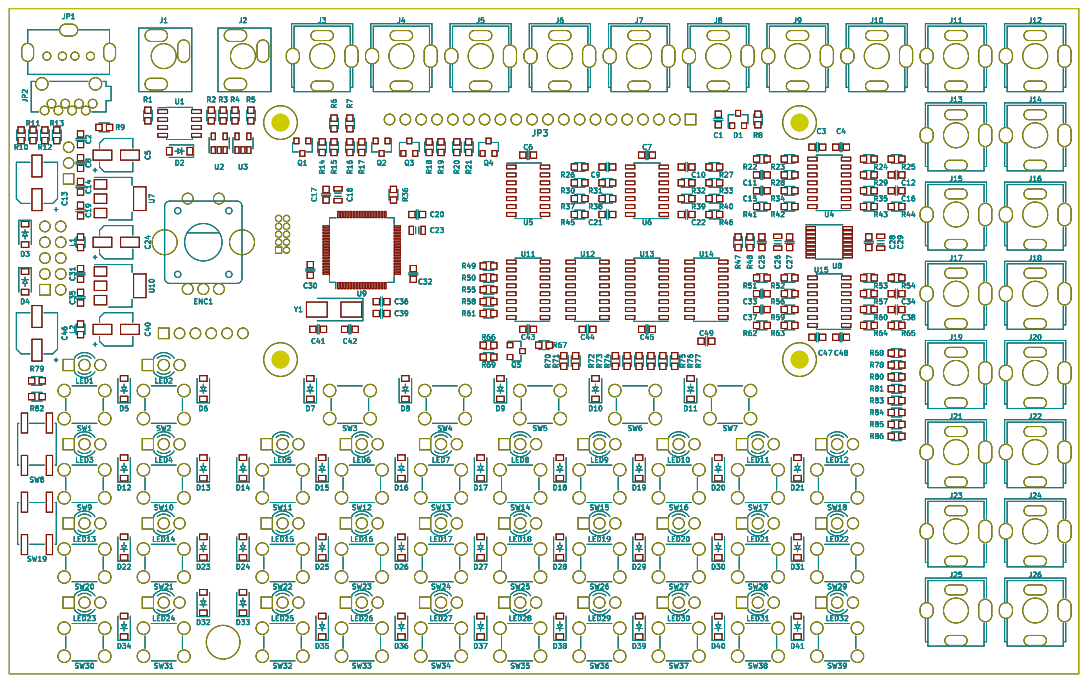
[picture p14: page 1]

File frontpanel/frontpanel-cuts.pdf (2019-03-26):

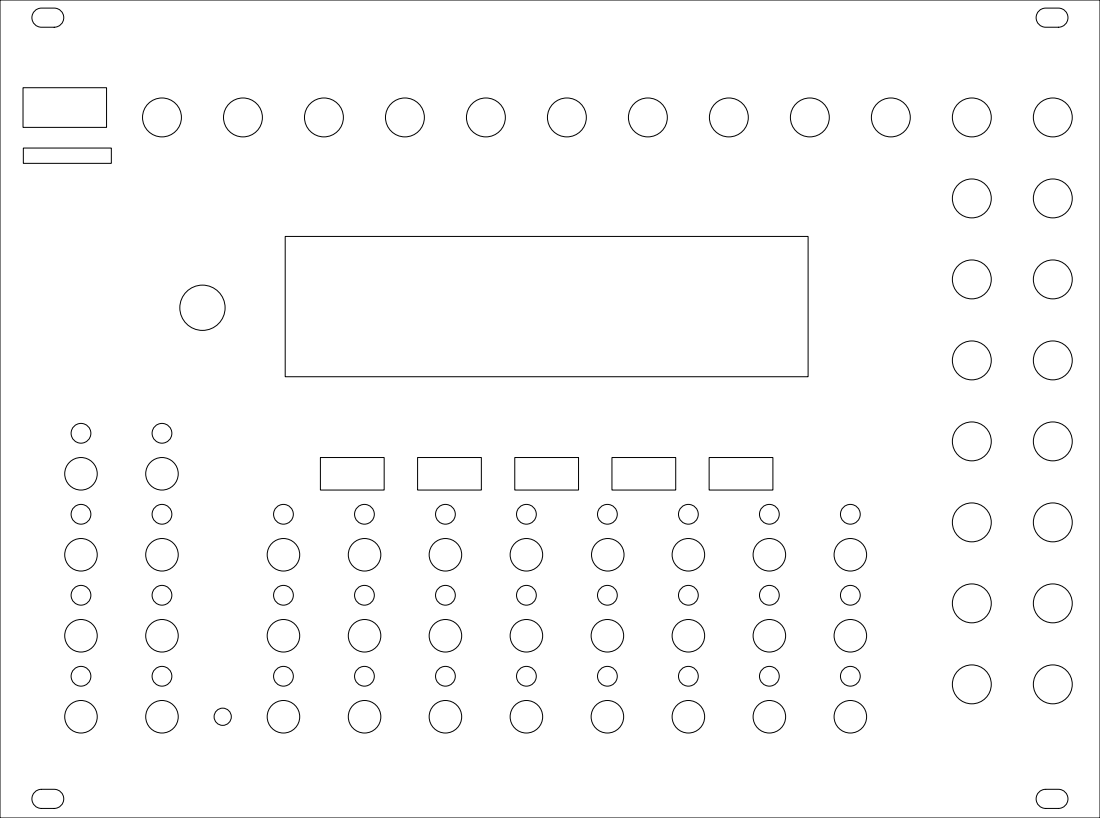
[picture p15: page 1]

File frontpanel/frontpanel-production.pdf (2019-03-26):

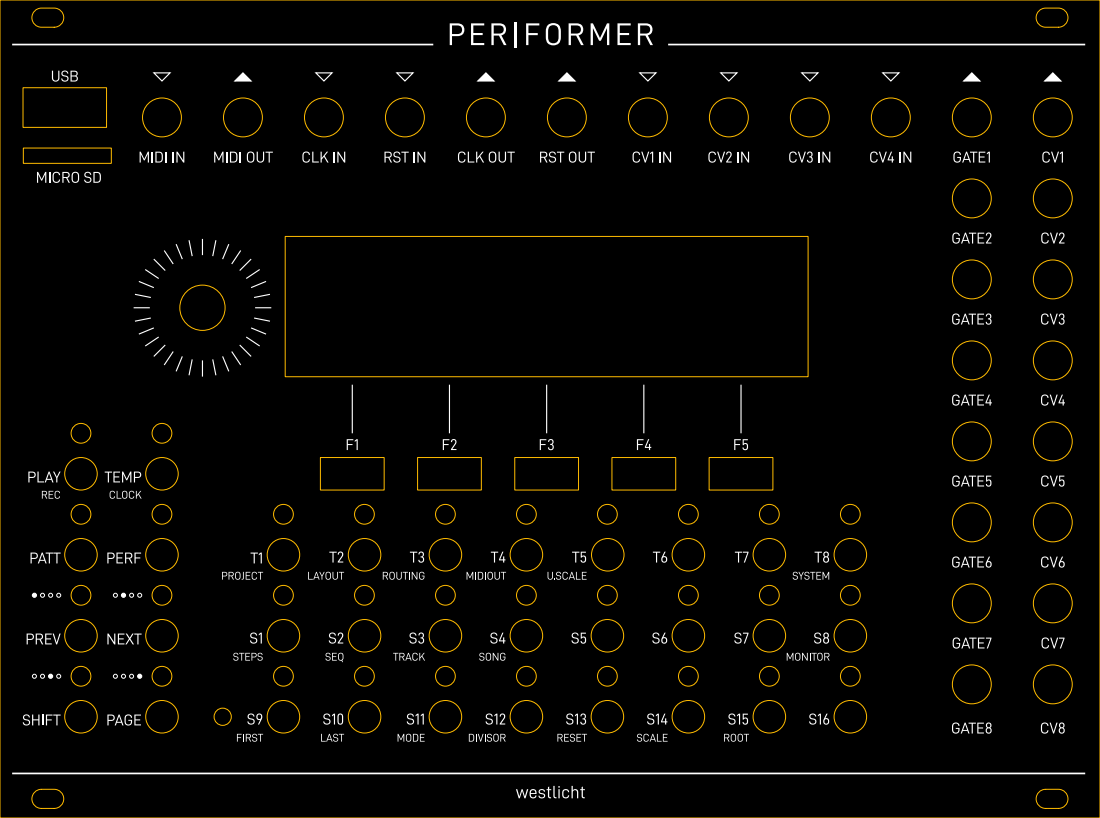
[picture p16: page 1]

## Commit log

2017-10-11 renamed to sequencer
    [button-matrix.sch, dac.sch, jacks.sch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]
2017-10-12 work on schematic
    [button-matrix.sch, dac.sch, jacks.sch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]
2017-10-14 work in progress
    [button-matrix.sch, dac.sch, jacks.sch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]
2017-10-14 more work
    [button-matrix.sch, dac.sch, mcu.sch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]
2017-10-20 more work on layout
    [dac.sch, jacks.sch, mcu.sch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]
2017-10-21 worked on label placement
    [sequencer.kicad_pcb]
2017-10-24 renamed led references D -> LED
    [led-matrix.sch, sequencer.kicad_pcb]
2017-10-24 renamed CV_INX to CVINX
    [jacks.sch, sequencer.kicad_pcb]
2017-10-24 renamed MIDIIN and MIDIOUT jacks
    [jacks.sch, sequencer.kicad_pcb]
2017-10-24 renamed clock/reset input/output jacks
    [jacks.sch, sequencer.kicad_pcb]
2017-10-26 redesign in progress
    [dac.sch, jacks.sch, mcu.sch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]
2017-10-26 only ground plane left
    [dac.sch, jacks.sch, mcu.sch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]
2017-10-28 layout redesign
    [sequencer.kicad_pcb]
2017-10-28 added frontpanel design
    [frontpanel.kicad_pcb]
2017-10-28 added silkscreen info
    [sequencer.kicad_pcb]
2017-10-28 renamed jacks
    [jacks.sch, sequencer.kicad_pcb]
2017-10-28 renamed header references to JPxxx
    [mcu.sch, power.sch, sequencer.kicad_pcb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]
2017-10-29 fixed invalid pin mapping on 74HC595
    [sequencer.kicad_pcb]
2017-10-29 last minute fixes
    [mcu.sch, sequencer.kicad_pcb, sequencer.sch]
2017-10-29 added separate USB 5V power trace
    [sequencer.kicad_pcb]
2017-10-30 work on frontpanel
    [frontpanel.kicad_pcb]
2017-10-30 last cleanup before sending to fab
    [frontpanel.kicad_pcb, sequencer.kicad_pcb]
2017-10-30 added images of the PCB and frontpanel
2017-10-30 added gerber files
    [frontpanel-Edge.Cuts.gm1, frontpanel-F.SilkS.gto, frontpanel-NPTH.drl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]
2017-10-31 updated part info
    [dac.sch, jacks.sch, mcu.sch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]
2017-10-31 added bom
    [bom.csv]
2017-10-31 fixed bom for rendering
    [bom.csv]
2017-10-31 added bom to readme
2017-11-20 replaced MCP6004 with TL074
    Fixes #1
    [jacks.sch]
2017-11-20 replaced OPA4172IPW with OPA4172IDR
    Fixes #6
    [dac.sch]
2018-05-08 all nets but GND connected
    [sequencer.kicad_pcb]
2018-05-08 moved +/-12V away from border
    [sequencer.kicad_pcb]
2018-05-09 replaced PJ301CM footprint
    [sequencer.kicad_pcb]
2018-05-10 updated footprints in schematic
    [jacks.sch]
2018-05-10 ground plane stitching
    [sequencer.kicad_pcb]
2018-05-10 added KiCAD and OSHW logos
    [sequencer.kicad_pcb]
2018-05-13 added Global schematic and only leave sheets in root schematic
    [Global.sch, sequencer.sch]
2018-05-13 updated due to new global sheet
    [button-matrix.sch, dac.sch, global.sch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]
2018-05-13 updated sheets numbering
    [button-matrix.sch, dac.sch, global.sch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]
2018-05-13 removed obsolete schematic file
    [matrix.sch]
2018-05-14 fixed ground plane connections
    [sequencer.kicad_pcb]
2018-05-14 another pass on reference labels
    [sequencer.kicad_pcb]
2018-05-15 renumbered pcb
    [button-matrix.sch, dac.sch, global.sch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]
2018-05-15 updated gerber files
    [frontpanel-Edge.Cuts.gm1, frontpanel-F.Mask.gts, frontpanel-F.SilkS.gto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]
2018-05-15 updated usb connector footprint on frontpanel
    [frontpanel.kicad_pcb]
2018-05-15 display settings
    [sequencer.kicad_pcb]
2018-05-15 fixed recom converter component
    [power.sch]
2018-05-15 updated boms
    [bom.csv]
2018-05-16 updated sheet title and revision and fixed 2 resistor descs
    [button-matrix.sch, dac.sch, global.sch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]
2018-06-14 corrected some part values
    [button-matrix.sch, global.sch]
2018-06-14 added cc-by-sa license to schematic sheets
    [button-matrix.sch, dac.sch, global.sch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]
2018-06-14 added package field
    [button-matrix.sch, dac.sch, global.sch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]
2018-06-14 updated bom with package
    [bom.csv]
2018-06-14 updated bom config
2018-08-26 use rail-to-rail opamp for cv inputs
    [jacks.sch, sequencer.kicad_pcb]
2018-08-26 renumbered components
    [dac.sch, global.sch, jacks.sch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]
2018-08-26 updated netlist
    [dac.sch, jacks.sch, sequencer.kicad_pcb]
2018-08-26 cleanup schematics and updated to revision 0.3
    [button-matrix.sch, dac.sch, global.sch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]
2018-08-26 tidy up JTAG section
    [sequencer.kicad_pcb]
2018-08-26 added schematic as pdf
2018-08-26 fixed schematic pdf link
2018-09-10 updated README and BOMs
    [bom.csv, hardware.csv]
2018-09-10 fixed hardware bom
    [hardware.csv]
2018-10-09 cleaned up schematics
    [button-matrix.sch, dac.sch, global.sch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]
2018-10-09 updated PCB to revision 1.0, made all mounting holes M2.5
    [sequencer.kicad_pcb]
2018-10-09 updated frontpanel to use oval mounting holes and M2.5 instead of M2
    [frontpanel.kicad_pcb]
2018-10-09 updated schematics PDF
2018-10-09 added silkscreen pdfs
2018-11-05 changed license to cc-by-nc-sa
    [button-matrix.sch, dac.sch, global.sch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]
2018-11-19 revised schematic and pcb
    - fixed clock/reset inputs
    - schematic annotations
    - moved to cc-by-nc-sa
    [button-matrix.sch, dac.sch, global.sch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]
2018-11-19 updated kicad libs
2018-11-19 updated silkscreen pdfs
2018-11-19 updated bom
    [bom.csv]
2018-12-21 updated schematic pdf
2019-01-06 updated frontpanel
    [frontpanel.kicad_pcb]
2019-01-06 fix frontpanel
    [frontpanel.kicad_pcb]
2019-01-06 updated frontpanel silkscreen
    [frontpanel.kicad_pcb]
2019-01-06 added frontpanel silkscreen library
2019-01-06 updated frontpanel gerber files
    [frontpanel-Edge.Cuts.gm1, frontpanel-F.Mask.gts, frontpanel-F.SilkS.gto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]
2019-01-06 pcb files cleanup
    [sequencer.kicad_pcb]
2019-01-06 updated pcb gerber files
    [sequencer-B.Cu.gbl, sequencer-B.Mask.gbs, sequencer-B.Paste.gbp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]
2019-01-07 updated title to PER|FORMER
    [button-matrix.sch, dac.sch, global.sch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]
2019-01-14 updated hardware bom
    [hardware.csv]
2019-03-17 updated schematics to kicad5
    [button-matrix.sch, dac.sch, global.sch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]
2019-03-17 updated netlist and main pcb to kicad5
    [sequencer.kicad_pcb]
2019-03-17 updated footprints to kicad5
    [dac.sch, global.sch, jacks.sch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]
2019-03-17 updated frontpanel to kicad5
    [frontpanel.kicad_pcb]
2019-03-18 updated kicad-libs
2019-03-18 added interactive bom
